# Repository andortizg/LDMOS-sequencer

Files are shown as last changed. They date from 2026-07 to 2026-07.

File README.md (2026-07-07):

# ATtiny85 TX/RX Sequencer for HF LDMOS Power Amplifier with overdrive protection

ATtiny85-based TX/RX sequencer for a 1KW HF LDMOS solid-state power amplifier. Provides safe relay sequencing, overdrive protection, and hardware watchdog supervision.

## Features

- Correct TX/RX relay sequencing to protect both the LDMOS transistor and the transceiver
- Overdrive input protection: blocks bias if input power exceeds threshold
- Hardware watchdog (250ms): returns to safe RX state if firmware hangs
- Fail-safe design: all relays return to bypass (RX) on power loss or STBY mode

## Hardware Integration

This sequencer is designed to work with the following boards:

- **SP6GK TX-RX Relay Board** — handles RF switching (RM85 relays), input SWR bridge, and overpower detection ([GitHub](https://github.com/SP6GK/TXRX_Relay_Board))
- **S21RC LDMOS SSPA Controller V2.1 Lite** — manages LDMOS bias, display, and secondary protections ([GitHub](https://github.com/s21rc/ldmos_sspa_controller_v2.1_lite))
- **DXWorld-e Protection Board** — hardware overcurrent, overvoltage, and VSWR protection via BTS50085 (30µs cutoff)

## Pin Mapping

| Pin | Arduino | Direction | Function |
|-----|---|---|---|
| PB0 | D0 | INPUT | OVERDRIVE — HIGH_PWR_IN from SP6GK board (active HIGH) |
| PB1 | D1 | OUTPUT | RF_RELAY_IN — TRX input relay via BC547→SP6GK PNP (HIGH=active) |
| PB2 | D2 | OUTPUT | PTT_OUT — PTT to S21RC controller (HIGH=TX, 12V) |
| PB3 | D3 | INPUT | PTT_IN — Operator PTT, active LOW (internal pull-up) |
| PB4 | D4 | OUTPUT | RF_RELAY_OUT — ANT output relay via BC547→SP6GK PNP (HIGH=active) |
| PB5 | — | — | RESET — do not use |

## TX Sequence

```
1. ANT output relay → TX     (no RF load, bias off)
2. Wait 10ms
3. TRX input relay  → TX
4. Wait 10ms
5. PTT_OUT → HIGH            (S21RC activates bias, keys transceiver)
6. Wait 15ms                 (bias stabilization margin)
→ RF active
```

## RX Sequence

```
1. PTT_OUT → LOW             (S21RC cuts bias, stops transceiver)
2. Wait 8ms                  (RF decay)
3. TRX input relay  → RX
4. Wait 10ms
5. ANT output relay → RX
```

## Overdrive Protection

The SP6GK board includes an overpower detector with adjustable threshold (via potentiometer) that drives the HIGH_PWR_IN signal HIGH when input power exceeds the set level.

When overdrive is detected during TX:

1. PTT_OUT is pulled LOW immediately
2. S21RC interprets this as end of TX and cuts LDMOS bias
3. RF relays remain in TX position (operator still holds PTT)
4. **Bias is not restored until the operator releases PTT** (manual reset required)

## STBY/OPER Switch

A normally-closed switch in series with PTT_IN provides STBY mode entirely in hardware:

- **OPER**: switch closed → normal operation
- **STBY**: switch open → PTT_IN never goes LOW → no TX sequence, bias never activated
- Relay coil power is also cut in STBY → RM85 relays return to NC (bypass) → antenna connected directly to transceiver

This is a fully fail-safe design: cable break or switch failure defaults to STBY/bypass.

## Bias Relay

The LDMOS gate bias line is switched by a dedicated relay controlled by the S21RC controller. The relay coil current is negligible (LDMOS gate is capacitive, leakage in µA range). A small signal relay (SRD-12VDC, HK19F, etc.) is sufficient.

The relay driver uses a BC547 NPN transistor in common-emitter configuration driven by PTT_OUT via the S21RC controller output, providing full galvanic isolation between the control circuitry and the LDMOS gate bias network.

## Watchdog

The ATtiny85 internal watchdog is enabled with a 250ms timeout. If the firmware hangs for any reason, the micro resets and `setup()` immediately drives all outputs to the safe RX state:

```
RF_RELAY_OUT → LOW  (ANT relay to bypass)
RF_RELAY_IN  → LOW  (TRX relay to bypass)
PTT_OUT      → LOW  (S21RC in RX, bias off)
```

## Requirements

- **Arduino IDE** with ATtiny85 board support ([ATTinyCore](https://github.com/SpenceKonde/ATTinyCore) recommended)
- **Clock**: 8MHz internal oscillator (no external crystal needed)
- **Fuses**: default — do not burn RSTDISBL (PB5/RESET must remain as reset pin)

## Programming

Use any ISP programmer (USBasp, Arduino as ISP) via the SPI header on PB0/PB1/PB2/PB5.

Board settings in Arduino IDE:
```
Board:     ATtiny85
Clock:     8 MHz (internal)
Programmer: USBasp (or Arduino as ISP)
```

## License

MIT License — feel free to use and modify for your own amplifier builds.

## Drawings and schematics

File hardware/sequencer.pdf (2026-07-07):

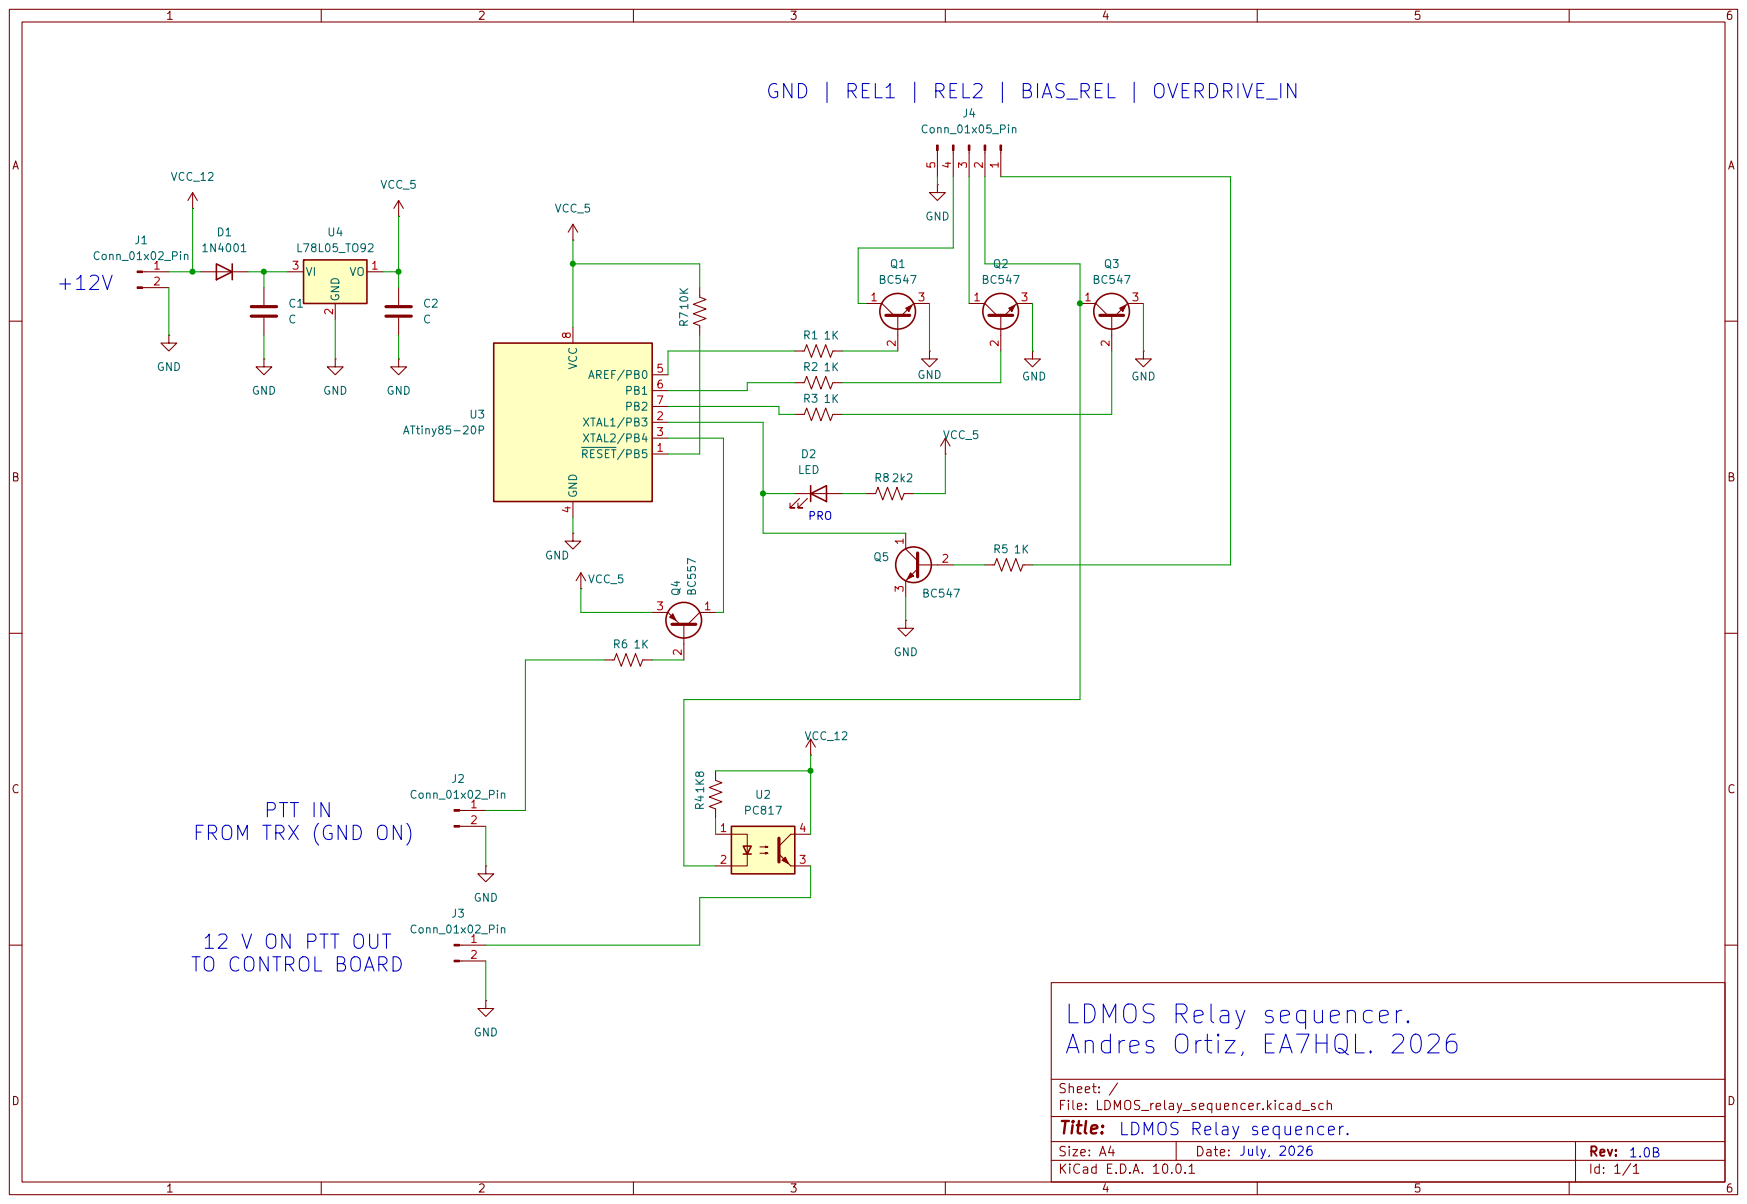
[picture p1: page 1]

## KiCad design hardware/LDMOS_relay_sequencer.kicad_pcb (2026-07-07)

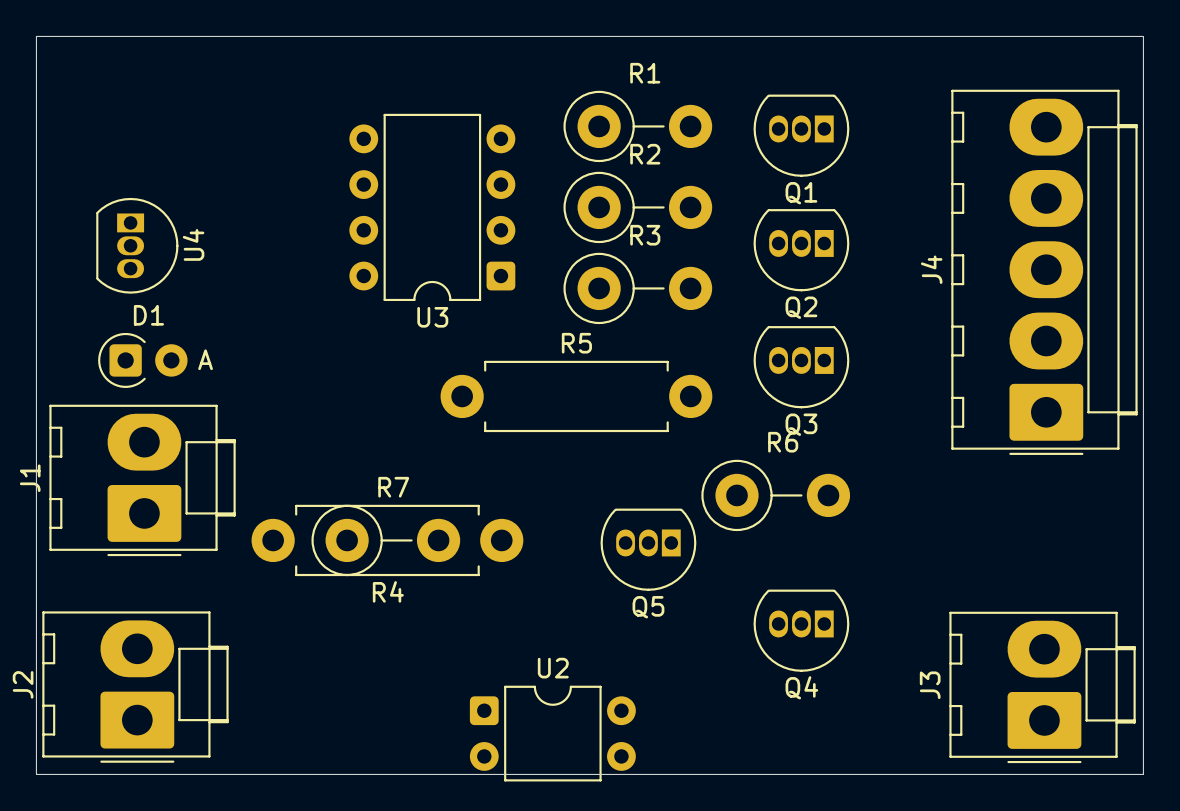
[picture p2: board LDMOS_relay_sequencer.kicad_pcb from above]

Board: 2 copper layers, 61.5 x 41.0 mm, 20 parts (0 on the bottom side), 22 nets, no tracks yet.

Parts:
D1: 1N4001; D_A-405_P2.54mm_Vertical_AnodeUp
J1, J2, J3: Conn_01x02_Pin; Molex_KK-396_A-41791-0002_1x02_P3.96mm_Vertical
J4: Conn_01x05_Pin; Molex_KK-396_A-41791-0005_1x05_P3.96mm_Vertical
Q1, Q2, Q3, Q5: BC547; TO-92_Inline
Q4: BC557; TO-92_Inline
R1, R2, R3, R6: 1K; R_Axial_DIN0411_L9.9mm_D3.6mm_P5.08mm_Vertical
R4: 1K8; R_Axial_DIN0411_L9.9mm_D3.6mm_P12.70mm_Horizontal
R5: 1K; R_Axial_DIN0411_L9.9mm_D3.6mm_P12.70mm_Horizontal
R7: 10K; R_Axial_DIN0411_L9.9mm_D3.6mm_P5.08mm_Vertical
U2: PC817; DIP-4_W7.62mm
U3: ATtiny85-20P; DIP-8_W7.62mm
U4: L78L05_TO92; TO-92_Inline

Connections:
GND: J1.2, J2.2, J3.2, J4.5, Q1.3 (E), Q2.3 (E), Q3.3 (E), Q5.3 (E), U3.4 (GND), U4.2 (GND)
unnamed: D1.1 (K), U4.3 (VI)
unnamed: J2.1, R6.1, U2.2
unnamed: J3.1, U2.3
unnamed: J4.1, R5.2
unnamed: J4.2, Q3.1 (C)
unnamed: J4.3, Q2.1 (C)
unnamed: J4.4, Q1.1 (C)
unnamed: Q1.2 (B), R1.2
unnamed: Q2.2 (B), R2.2
unnamed: Q3.2 (B), R3.2
unnamed: Q4.2 (B), R6.2
unnamed: Q4.1 (C), U3.3 (XTAL2/PB4)
unnamed: Q5.2 (B), R5.1
unnamed: Q5.1 (C), U3.2 (XTAL1/PB3)
unnamed: R4.1, U2.1
unnamed: R1.1, U3.5 (AREF/PB0)
unnamed: R2.1, U3.6 (PB1)
unnamed: R3.1, U3.7 (PB2)
unnamed: R7.1, U3.1 (~RESET/PB5)
VCC_5: Q4.3 (E), R7.2, U3.8 (VCC), U4.1 (VO)
VCC_12: D1.2 (A), J1.1, R4.2, U2.4

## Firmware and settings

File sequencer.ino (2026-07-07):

#include <avr/wdt.h>

// TX/RX Sequencer for 1KW HF LDMOS Power Amplifier - ATtiny85
//
// Pin mapping:
// PB0 (pin5) - OVERDRIVE   : HIGH_PWR_IN from SP6GK TX-RX board, active HIGH
// PB1 (pin6) - RF_RELAY_IN : Input relay (TRX side) via BC547→PNP SP6GK (HIGH=active)
// PB2 (pin7) - PTT_OUT     : PTT signal to S21RC controller (HIGH=TX, 12V)
// PB3 (pin2) - PTT_IN      : Operator PTT input, active LOW (internal pull-up)
//                            Wired in series with STBY/OPER switch (NC=OPER)
// PB4 (pin3) - RF_RELAY_OUT: Output relay (ANT side) via BC547→PNP SP6GK (HIGH=active)
// PB5        - RESET, do not use
//
// Notes:
// - RF_RELAY_IN and RF_RELAY_OUT drive BC547 NPN transistors in common-emitter config
//   which pull the base of PNP drivers on the SP6GK board to GND, activating the RM85 relays
// - PTT_OUT drives the S21RC SSPA controller bias line (12V = TX active)
//   The S21RC controller activates the LDMOS bias and keys the transceiver
// - In STBY position, the STBY/OPER switch opens the PTT_IN line → micro never sees TX
//   and relay coil power is cut → RM85 relays return to NC (bypass) position
// - Overdrive protection (from SP6GK overpower detector) blocks PTT_OUT to S21RC
//   which interprets it as end of TX and cuts the LDMOS bias
//   Bias is NOT restored until operator releases PTT (manual reset required)
// - Hardware watchdog (250ms) resets the micro if firmware hangs,
//   returning all outputs to safe RX state via setup() initialization

#define OVERDRIVE    0
#define RF_RELAY_IN  1
#define PTT_OUT      2
#define PTT_IN       3
#define RF_RELAY_OUT 4

// Sequence timing in ms
#define T_RELAY     10   // RM85 mechanical relay switching time
#define T_BIAS      15   // margin for S21RC bias stabilization
#define T_RF_DECAY   8   // RF decay time after transceiver stops transmitting

bool inTX       = false;
bool biasKilled = false;  // true if PTT blocked due to overdrive protection

void setup() {
  wdt_disable();

  pinMode(OVERDRIVE,    INPUT);
  pinMode(RF_RELAY_IN,  OUTPUT);
  pinMode(PTT_OUT,      OUTPUT);
  pinMode(PTT_IN,       INPUT_PULLUP);
  pinMode(RF_RELAY_OUT, OUTPUT);

  // Safe initial state: RX
  // SP6GK relays in NC (bypass) position when BC547 is OFF
  digitalWrite(RF_RELAY_OUT, LOW);
  digitalWrite(RF_RELAY_IN,  LOW);
  digitalWrite(PTT_OUT,      LOW);  // LOW = S21RC in RX mode, bias OFF

  wdt_enable(WDTO_250MS);
}

// TX sequence:
//   1. ANT output relay switches to TX (no RF load, bias off)
//   2. TRX input relay switches to TX
//   3. PTT sent to S21RC (activates bias and keys transceiver)
void goTX() {
  digitalWrite(RF_RELAY_OUT, HIGH);
  delay(T_RELAY);
  wdt_reset();

  digitalWrite(RF_RELAY_IN, HIGH);
  delay(T_RELAY);
  wdt_reset();

  digitalWrite(PTT_OUT, HIGH);   // S21RC activates bias and transmits
  delay(T_BIAS);
  wdt_reset();

  inTX       = true;
  biasKilled = false;
}

// RX sequence:
//   1. PTT to S21RC released (S21RC cuts bias and stops transceiver)
//   2. Wait for RF decay
//   3. TRX input relay returns to RX
//   4. ANT output relay returns to RX
void goRX() {
  digitalWrite(PTT_OUT, LOW);    // S21RC cuts bias and stops transceiver
  delay(T_RF_DECAY);
  wdt_reset();

  digitalWrite(RF_RELAY_IN, LOW);
  delay(T_RELAY);
  wdt_reset();

  digitalWrite(RF_RELAY_OUT, LOW);

  inTX       = false;
  biasKilled = false;
}

// Overdrive protection: blocks PTT signal to S21RC
// S21RC interprets this as end of TX and cuts LDMOS bias
// Operator must release PTT to reset this condition
void killBias() {
  digitalWrite(PTT_OUT, LOW);
  biasKilled = true;
}

void loop() {
  wdt_reset();

  bool pttActive       = (digitalRead(PTT_IN)   == LOW);
  bool overdriveActive = (digitalRead(OVERDRIVE) == HIGH);

  // Overdrive protection: requires PTT release to reset
  if (inTX && overdriveActive && !biasKilled) {
    killBias();
  }

  // PTT management
  if (pttActive && !inTX) {
    goTX();
  } else if (!pttActive && inTX) {
    goRX();
  }
}
